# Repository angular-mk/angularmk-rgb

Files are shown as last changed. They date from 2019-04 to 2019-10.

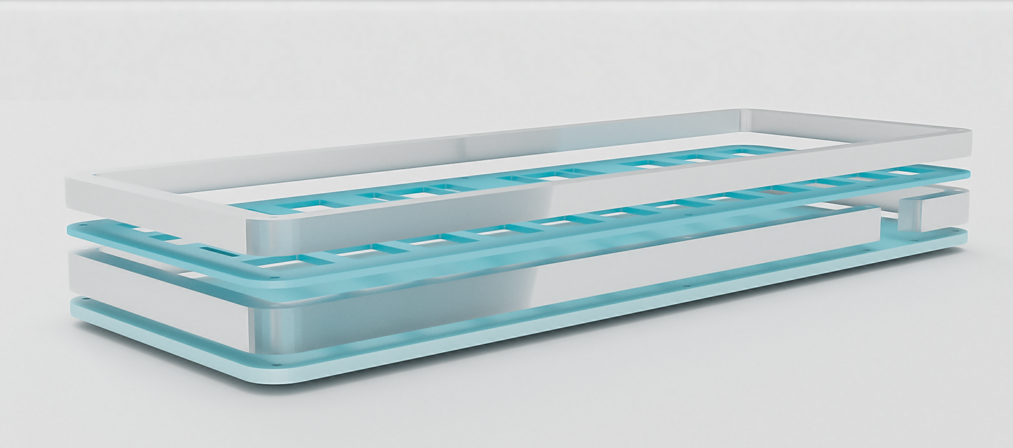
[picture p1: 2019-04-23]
Case Design/Render 2.png

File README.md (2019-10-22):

# angularmk-rgb
## Angular RGB Mechanical Keyboard

Image of the Keyboard

### Description

The AngularRGB is a, minimalistic, 40% keyboard that supports perkey RGB Lighting. We've noticed that there are no purchasing options for anyone interested in a rgb per key backlit keyboard, so we decided to create one.
[Website Description](https://angularmk.xyz/angular-rgb/)

Keyboard PCB

The PCB consists of a 4x12 matrix layed out as a COL to ROW diode configuration with a staggered design. Additionally, there are slots cut out on the board to provide the space for the WS2812B-Mini RGB LEDs that provide the lighting. There are also numerous protection features, such as ESD protections for both the data lines aswell as the power lines; fueses protecting the precious microcontroller in a case of short circuit; and many more.

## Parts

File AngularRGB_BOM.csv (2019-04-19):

Id | Designator | Package | Quantity | Designation | Supplier and ref
1 | SW28,SW31,SW2,SW3,SW4,SW5,SW6,SW7,SW8,SW9,SW10,SW11,SW12,SW13,SW14,SW15,SW16,SW17,SW18,SW19,SW20,SW21,SW22,SW23,SW24,SW25,SW26,SW27,SW29,SW30,SW32,SW33 | MX-1U | 32 | MX_1U
2 | Y1 | Crystal_SMD_3225-4Pin_3.2x2.5mm | 1 | Crystal_GND24
3 | C1,C5 | C_0603_1608Metric | 2 | 1u
4 | C2,C3 | C_0603_1608Metric | 2 | 20pF
5 | C4,C6,C7,C8,C9,C10,C11,C12,C13,C14,C15,C16 | C_0603_1608Metric | 12 | 100n
6 | D1 | D_SOD-123F | 1 | D
7 | D2,D3,D4,D5,D6,D7,D8,D9,D10,D11,D12,D13,D14,D15,D16,D17,D18,D19,D20,D21,D22,D23,D24,D25,D26,D27,D28,D29,D30,D31,D32,D33,D34,D35,D36,D37,D38,D39,D40,D41,D42 | D_SOD-123 | 41 | D
8 | F1 | Fuse_0603_1608Metric | 1 | Fuse
9 | R1,R2,R3,R4 | R_0603_1608Metric | 4 | 5k1
10 | R5,R6 | R_0603_1608Metric | 2 | 22
11 | SW1.25U1,SW1.25U2,SW1.25U3,SW1.25U4,SW1.25U5,SW1.25U6 | MX_1.25U | 6 | MX_1.25U
12 | SW1.75U1,SW1.75U2 | MX-1.75U | 2 | MX_1.75U
13 | U1 | QFN-44-1EP_7x7mm_P0.5mm_EP5.2x5.2mm | 1 | ATmega32U4-MU
14 | U2 | SOT-23-6 | 1 | USB6B1
15 | USB1 | HRO-TYPE-C-31-M-12-Assembly | 1 | HRO-TYPE-C-31-M-12
16 | SW2.25U1 | MX-2.25U | 1 | MX_2.25U
17 | SW2.75U1 | MX-2.75U | 1 | MX_2.75U
18 | SW1 | SPST-NO-4 | 1 | SW_Push
19 | H1,H2,H3,H4,H5,H6,H7,H8,H9,H10 | MountingHole_2.2mm_M2_DIN965_Pad | 10 | MountingHole_Pad
20 | LED1,LED5,LED8,LED12,LED16,LED20,LED24,LED28,LED32,LED36,LED40,LED43,LED2,LED6,LED9,LED13,LED17,LED21,LED25,LED29,LED33,LED37,LED44,LED3,LED10,LED14,LED18,LED22,LED26,LED30,LED34,LED38,LED41,LED45,LED4,LED7,LED11,LED19,LED23,LED27,LED31,LED35,LED39,LED42,LED46 | REVERSE_LED | 45 | WS2812
21 | J1 | PinSocket_1x09_P2.54mm_Vertical | 1 | Conn_01x09_Male
22 | TP1,TP2 | TestPoint_Pad_D2.0mm | 2 | TestPoint

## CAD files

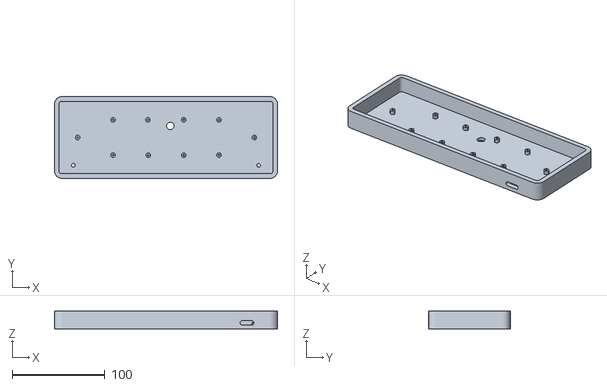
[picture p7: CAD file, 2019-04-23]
Case Design/Multilayer Sandwich Case/AlCase High Profile.stl
240.5 x 88.2 x 19.0

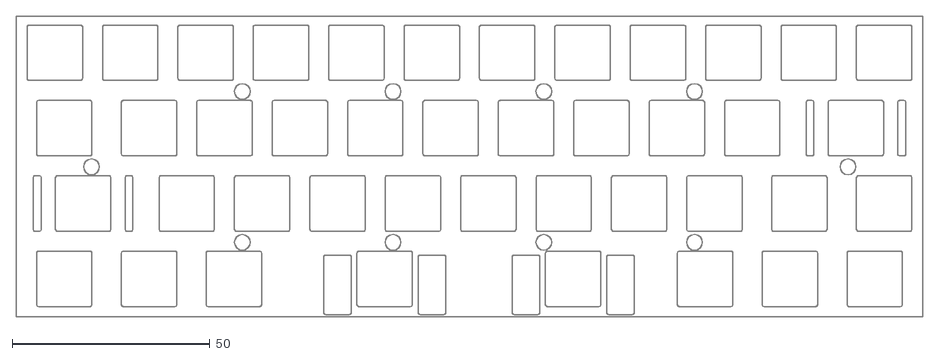
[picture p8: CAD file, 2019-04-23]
Case Design/Top_Plate.dxf
229.0 x 76.0

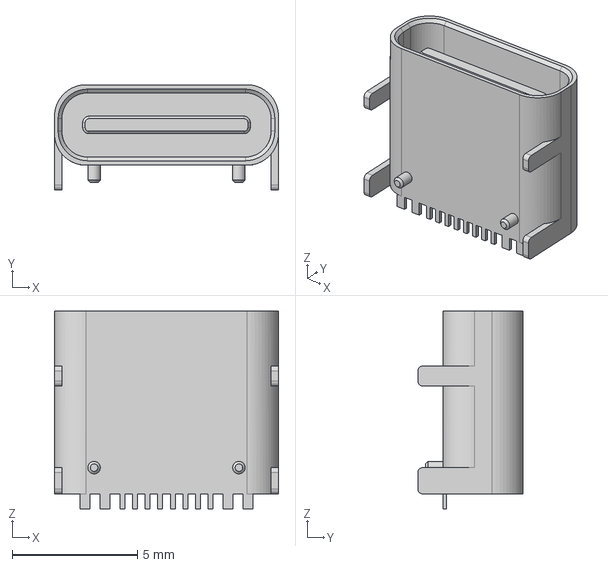
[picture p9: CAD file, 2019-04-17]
Type-C.pretty-master/HRO TYPE-C-31-M-12.step
8.94 x 4.21 x 7.90 mm

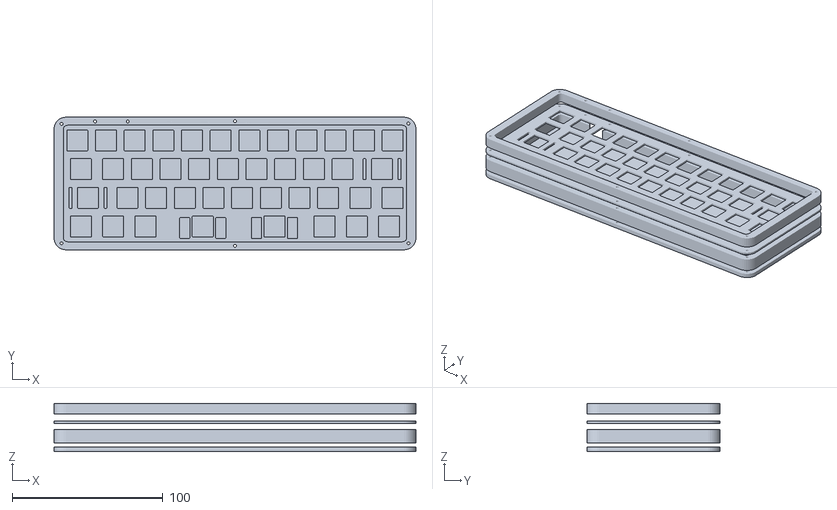
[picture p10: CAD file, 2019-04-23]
Case Design/Multilayer Sandwich Case/AlCase Sandwich.stl
240.5 x 88.2 x 32.1

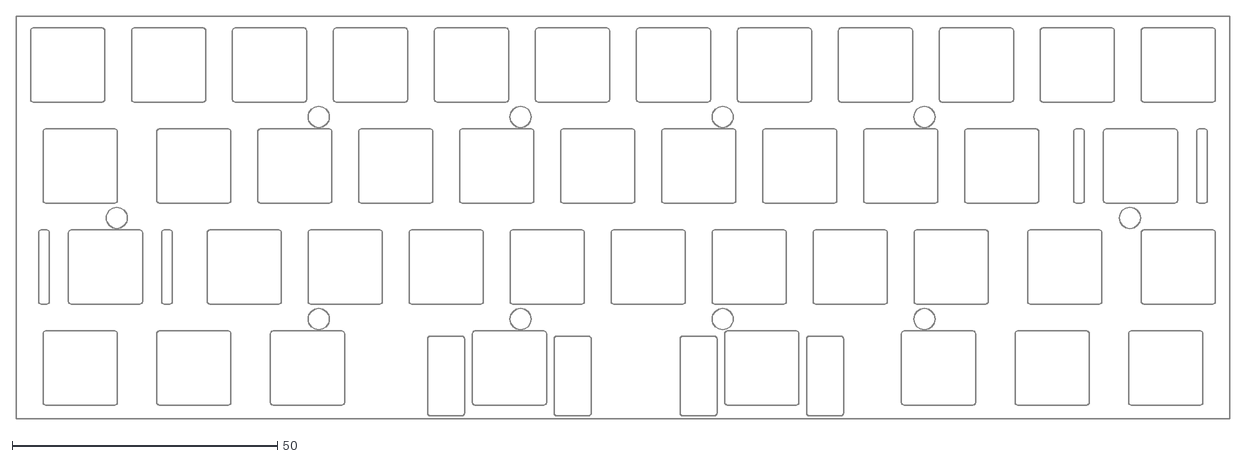
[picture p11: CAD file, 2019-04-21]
Case Design/Rounded Top Plate.dxf
229.0 x 76.0

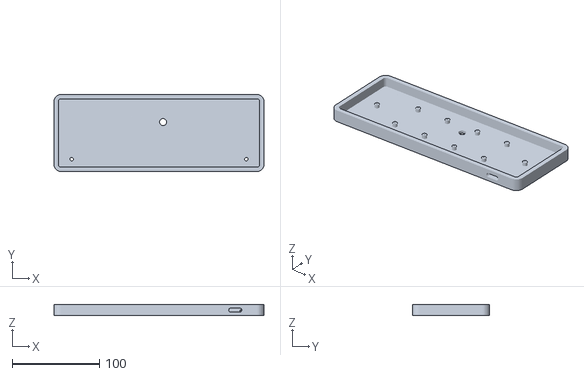
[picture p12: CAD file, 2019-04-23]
Case Design/Multilayer Sandwich Case/AlCase Low Profile.stl
240.5 x 88.2 x 13.1

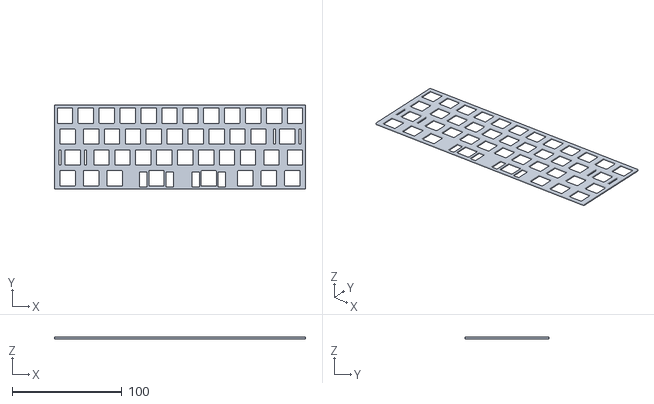
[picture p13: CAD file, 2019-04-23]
Case Design/Multilayer Sandwich Case/Plate Filled.stl
228.6 x 76.2 x 1.50

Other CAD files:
Case Design/Multilayer Sandwich Case/AlCase - Low.blend
Case Design/Multilayer Sandwich Case/AlCase - Sandwich.blend
Case Design/Multilayer Sandwich Case/AlCase.blend

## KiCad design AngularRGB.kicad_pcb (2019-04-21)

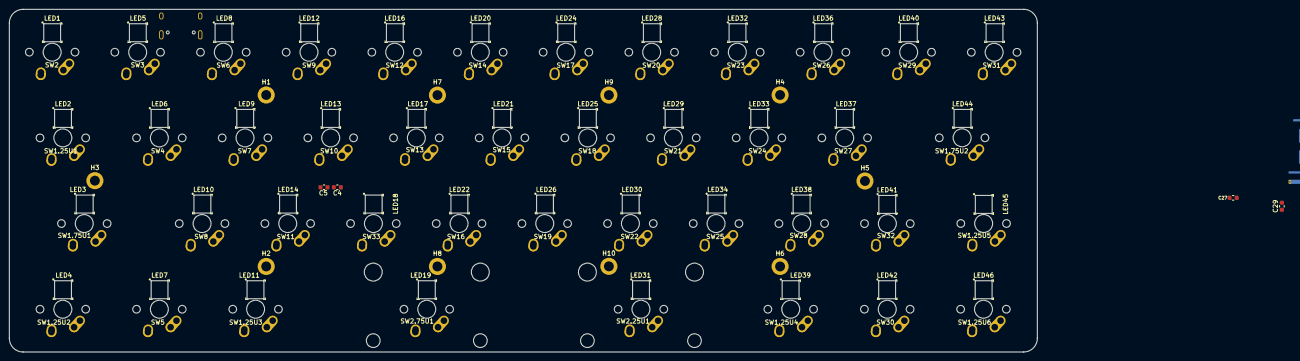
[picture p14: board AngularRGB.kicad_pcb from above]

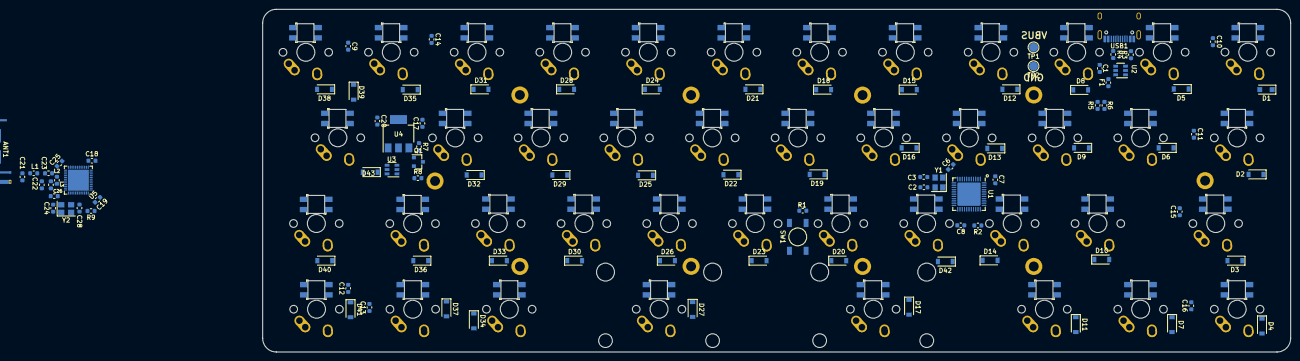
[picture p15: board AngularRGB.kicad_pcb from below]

Board: 4 copper layers, 228.6 x 76.2 mm, 192 parts (94 on the bottom side), 135 nets, no tracks yet.

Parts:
ANT1: SWRA117D; Texas_SWRA117D_2.4GHz_Right
C1, C5, C17, C20: 1u; C_0603_1608Metric
C2, C3: 20pF; C_0603_1608Metric
C4, C6, C7, C8, C9, C10, C11, C12, C13, C14, C15, C16, C18, C19, C25: 100n; C_0603_1608Metric
C21: 1.5pF; C_0603_1608Metric
C22: 1.0pF; C_0603_1608Metric
C23: 2.2pF; C_0603_1608Metric
C24, C28: 12pF; C_0603_1608Metric
C26: 2.2nF; C_0603_1608Metric
C27: 47n; C_0603_1608Metric
C29: 1.0n; C_0603_1608Metric
D1: D; D_SOD-123F
D2, D3, D4, D5, D6, D7, D8, D9, D10, D11, D12, D13, D14, D15, D16, D17, D18, D19, D20, D21, D22, D23, D24, D25, D26, D27, D28, D29, D30, D31, D32, D33, D34, D35, D36, D37, D38, D39, D40, D41, D42, D43: D; D_SOD-123
F1: Fuse; Fuse_0603_1608Metric
H1, H2, H3, H4, H5, H6, H7, H8, H9, H10: MountingHole_Pad; MountingHole_2.2mm_M2_DIN965_Pad
L1: 3.3nH; L_0603_1608Metric
L2: 4.7nH; L_0603_1608Metric
L3: 10nH; L_0603_1608Metric
LED1, LED2, LED3, LED4, LED5, LED6, LED7, LED8, LED9, LED10, LED11, LED12, LED13, LED14, LED16, LED17, LED18, LED19, LED20, LED21, LED22, LED24, LED25, LED26, LED28, LED29, LED30, LED31, LED32, LED33, LED34, LED36, LED37, LED38, LED39, LED40, LED41, LED42, LED43, LED44, LED45, LED46: WS2812; REVERSE_LED
Q1: BSS138; SOT-23
R1, R2, R3, R4, R7, R8, R9: 5k1; R_0603_1608Metric
R5, R6: 22; R_0603_1608Metric
SW1: SW_Push; SPST-NO-4
SW1.25U1, SW1.25U2, SW1.25U3, SW1.25U4, SW1.25U5, SW1.25U6: MX_1.25U
SW1.75U1, SW1.75U2: MX_1.75U; MX-1.75U
SW2, SW3, SW4, SW5, SW6, SW7, SW8, SW9, SW10, SW11, SW12, SW13, SW14, SW15, SW16, SW17, SW18, SW19, SW20, SW21, SW22, SW23, SW24, SW25, SW26, SW27, SW28, SW29, SW30, SW31, SW32, SW33: MX_1U; MX-1U
SW2.25U1: MX_2.25U; MX-2.25U
SW2.75U1: MX_2.75U; MX-2.75U
TP1, TP2: TestPoint; TestPoint_Pad_D2.0mm
U1: ATmega32U4-MU; QFN-44-1EP_7x7mm_P0.5mm_EP5.2x5.2mm
U2: USB6B1; SOT-23-6
U3: 74LVC2G34; SOT-23-6
U4: AMS1117-3.3; SOT-223-3_TabPin2
U5: nRF51x22-QFxx; QFN-48-1EP_6x6mm_P0.4mm_EP4.66x4.66mm
USB1: HRO-TYPE-C-31-M-12; HRO-TYPE-C-31-M-12-Assembly
Y1, Y2: Crystal_GND24; Crystal_SMD_3225-4Pin_3.2x2.5mm

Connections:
+3V3: C18.1, C19.1, C20.1, C29.1, Q1.1, R7.1, R9.1, U3.5, U4.2, U5.1, U5.12, U5.35, U5.36
/ANT: ANT1.1, C21.1, L1.1
/ANT1: C23.1, L2.1, U5.31
/ANT2: L2.2, L3.1, U5.32
/CS: D43.1, U1.29
/CS_3V: D43.2, R9.2, U5.43
/D+: R5.1, U1.4
/D-: R6.1, U1.3
/DN_PRE: U2.4, USB1.5, USB1.7
/DP_PRE: U2.6, USB1.6, USB1.8
/D_N: R6.2, U2.3
/D_P: R5.2, U2.1
/MISO: U1.11, U5.41
/MOSI: U1.10, U3.3
/MOSI_3V: U3.4, U5.42
/RST: Q1.3, R8.2, U1.1
/SCK: U1.9, U3.1
/SCK_3V: U3.6, U5.40
/SWDIO: Q1.2, R7.2, U5.23
/UCAP: C5.1, U1.6
/VBUS: F1.2, TP1.1, U2.5, USB1.2, USB1.11
/VDD_PA: C26.1, L3.2, U5.30
/XC1: C24.1, U5.37, Y2.1
/XC2: C28.1, U5.38, Y2.3
/XTAL1: C2.1, U1.17, Y1.1
/XTAL2: C3.1, U1.16, Y1.3
C0: D1.1, D2.1, D3.1, D4.1, U1.25
C1: D5.1, D6.1, D7.1, U1.26
C2: D8.1, D9.1, D10.1, D11.1, U1.27
C3: D12.1, D13.1, D14.1, U1.28
C4: D15.1, D16.1, D17.1, D42.1, U1.41
C5: D18.1, D19.1, D20.1, U1.40
C6: D21.1, D22.1, D23.1, U1.39
C7: D24.1, D25.1, D26.1, D27.1, U1.38
C8: D28.1, D29.1, D30.1, U1.37
C9: D31.1, D32.1, D33.1, D34.1, U1.36
C10: D35.1, D36.1, D37.1, U1.32
C11: D38.1, D39.1, D40.1, D41.1, U1.31
GND: ANT1.2, C1.2, C2.2, C3.2, C4.2, C5.2, C6.2, C7.2, C8.2, C9.2, C10.2, C11.2, C12.2, C13.1, C14.1, C15.1, C16.1, C17.2, C18.2, C19.2, C20.2, C21.2, C22.2, C24.2, C25.2, C26.2, C27.2, C28.2, C29.2, H1.1, H2.1, H3.1, H4.1, H5.1, H6.1, H7.1, H8.1, H9.1, H10.1, LED1.3, LED2.3, LED3.3, LED4.3, LED5.3, LED6.3, LED7.3, LED8.3, LED9.3, LED10.3, LED11.3, LED12.3, LED13.3, LED14.3, LED16.3, LED17.3, LED18.3, LED19.3, LED20.3, LED21.3, LED22.3, LED24.3, LED25.3, LED26.3, LED28.3, LED29.3, LED30.3, LED31.3, LED32.3, LED33.3, LED34.3, LED36.3, LED37.3, LED38.3, LED39.3, LED40.3, LED41.3, LED42.3, LED43.3, LED44.3, LED45.3, LED46.3, R2.2, R3.1, R4.2, SW1.1, TP2.1, U1.5, U1.15, U1.23, U1.35, U1.43, U1.45, U2.2, U3.2, U4.1, U5.13, U5.33, U5.34, U5.49, USB1.1, USB1.12, USB1.13, Y1.2, Y1.4, Y2.2, Y2.4
LED_INPUT: LED1.4, U1.8
unnamed: C22.1, C23.2, L1.2
unnamed: C25.1, U5.29
unnamed: C27.1, U5.39
unnamed: D1.2, SW2.2
unnamed: D2.2, SW1.25U1.2
unnamed: D3.2, SW1.75U1.2
unnamed: D4.2, SW1.25U2.2
unnamed: D5.2, SW3.2
unnamed: D6.2, SW4.2
unnamed: D7.2, SW5.2
unnamed: D8.2, SW6.2
unnamed: D9.2, SW7.2
unnamed: D10.2, SW8.2
unnamed: D11.2, SW1.25U3.2
unnamed: D12.2, SW9.2
unnamed: D13.2, SW10.2
unnamed: D14.2, SW11.2
unnamed: D15.2, SW12.2
unnamed: D16.2, SW13.2
unnamed: D17.2, SW2.75U1.2
unnamed: D18.2, SW14.2
unnamed: D19.2, SW15.2
unnamed: D20.2, SW16.2
unnamed: D21.2, SW17.2
unnamed: D22.2, SW18.2
unnamed: D23.2, SW19.2
unnamed: D24.2, SW20.2
unnamed: D25.2, SW21.2
unnamed: D26.2, SW22.2
unnamed: D27.2, SW2.25U1.2
unnamed: D28.2, SW23.2
unnamed: D29.2, SW24.2
unnamed: D30.2, SW25.2
unnamed: D31.2, SW26.2
unnamed: D32.2, SW27.2
unnamed: D33.2, SW28.2
unnamed: D34.2, SW1.25U4.2
unnamed: D35.2, SW29.2
unnamed: D36.2, SW32.2
unnamed: D37.2, SW30.2
unnamed: D38.2, SW31.2
unnamed: D39.2, SW1.75U2.2
unnamed: D40.2, SW1.25U5.2
unnamed: D41.2, SW1.25U6.2
unnamed: D42.2, SW33.2
unnamed: LED1.2, LED5.4
unnamed: LED2.2, LED6.4
unnamed: LED2.4, LED43.2
unnamed: LED3.4, LED44.2
unnamed: LED4.2, LED7.4
unnamed: LED4.4, LED45.2
unnamed: LED5.2, LED8.4
unnamed: LED6.2, LED9.4
unnamed: LED10.2, LED14.4
unnamed: LED3.2, LED10.4
unnamed: LED11.2, LED19.4
unnamed: LED7.2, LED11.4
unnamed: LED12.2, LED16.4
unnamed: LED8.2, LED12.4
unnamed: LED13.2, LED17.4
unnamed: LED9.2, LED13.4
unnamed: LED14.2, LED18.4
unnamed: LED16.2, LED20.4
unnamed: LED17.2, LED21.4
unnamed: LED18.2, LED22.4
unnamed: LED19.2, LED31.4
unnamed: LED20.2, LED24.4
unnamed: LED21.2, LED25.4
unnamed: LED22.2, LED26.4
unnamed: LED24.2, LED28.4
unnamed: LED25.2, LED29.4
unnamed: LED26.2, LED30.4
unnamed: LED28.2, LED32.4
unnamed: LED29.2, LED33.4
unnamed: LED30.2, LED34.4
unnamed: LED31.2, LED39.4
unnamed: LED32.2, LED36.4
unnamed: LED33.2, LED37.4
unnamed: LED34.2, LED38.4
unnamed: LED36.2, LED40.4
unnamed: LED37.2, LED44.4
unnamed: LED38.2, LED41.4
unnamed: LED39.2, LED42.4
unnamed: LED40.2, LED43.4
unnamed: LED41.2, LED45.4
unnamed: LED42.2, LED46.4
unnamed: R1.2, SW1.2, U1.13
unnamed: R2.1, U1.33
unnamed: R3.2, USB1.4
unnamed: R4.1, USB1.10
R0: SW2.1, SW3.1, SW6.1, SW9.1, SW12.1, SW14.1, SW17.1, SW20.1, SW23.1, SW26.1, SW29.1, SW31.1, U1.22
R1: SW1.25U1.1, SW1.75U2.1, SW4.1, SW7.1, SW10.1, SW13.1, SW15.1, SW18.1, SW21.1, SW24.1, SW27.1, U1.21
R2: SW1.25U5.1, SW1.75U1.1, SW8.1, SW11.1, SW16.1, SW19.1, SW22.1, SW25.1, SW28.1, SW32.1, SW33.1, U1.20
R3: SW1.25U2.1, SW1.25U3.1, SW1.25U4.1, SW1.25U6.1, SW2.25U1.1, SW2.75U1.1, SW5.1, SW30.1, U1.12
VCC: C1.1, C4.1, C6.1, C7.1, C8.1, C9.1, C10.1, C11.1, C12.1, C13.2, C14.2, C15.2, C16.2, C17.1, F1.1, LED1.1, LED2.1, LED3.1, LED4.1, LED5.1, LED6.1, LED7.1, LED8.1, LED9.1, LED10.1, LED11.1, LED12.1, LED13.1, LED14.1, LED16.1, LED17.1, LED18.1, LED19.1, LED20.1, LED21.1, LED22.1, LED24.1, LED25.1, LED26.1, LED28.1, LED29.1, LED30.1, LED31.1, LED32.1, LED33.1, LED34.1, LED36.1, LED37.1, LED38.1, LED39.1, LED40.1, LED41.1, LED42.1, LED43.1, LED44.1, LED45.1, LED46.1, R1.1, R8.1, U1.2, U1.7, U1.14, U1.24, U1.34, U1.44, U4.3

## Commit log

2019-04-16 MCU Connections
    [AngularRGB.sch]
2019-04-16 USB Sch
    [AngularRGB.sch]
2019-04-17 USB Port
    [AngularRGB.sch]
2019-04-17 Matrix Layout
    [AngularRGB.sch]
2019-04-17 Addded PCB Footprints
2019-04-17 Footprint Linking
    [AngularRGB.sch, HRO TYPE-C-31-M-12.step]
2019-04-18 WS2812B-Mini Symbole
    [AngularRGB.sch]
2019-04-18 Reverse mount WS2812B LED Footprint
    [AngularRGB.kicad_pcb, AngularRGB.sch]
2019-04-18 Led matrix
    [AngularRGB.sch, LedMatrix.sch]
2019-04-18 LED Matrix Sch
    [AngularRGB.sch]
2019-04-18 LED Matrix Placement
    [AngularRGB.kicad_pcb, AngularRGB.sch]
2019-04-18 LED Matrix Footprint swap
    [AngularRGB.kicad_pcb]
2019-04-18 Matrix Connections
    [AngularRGB.kicad_pcb, AngularRGB.sch]
2019-04-19 Finsihed Layout
    [AngularRGB.kicad_pcb, AngularRGB.sch]
2019-04-19 Copper Pour
    [AngularRGB.kicad_pcb]
2019-04-19 Fixed LED Input
    [AngularRGB-B.Cu.gbr, AngularRGB-B.Mask.gbr, AngularRGB-B.Paste.gbr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]
2019-04-20 Top Plate Init
    [Top_Plate.dxf]
2019-04-21 Added Case Design
    [AlCase.blend, AngularRGB.kicad_pcb, AngularRGB.sch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]
2019-04-22 Added the case
    [AlCase.blend]
2019-04-23 Cleaning up
    [AlCase - Low.blend, AlCase - Sandwich.blend, AlCase.blend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]
2019-04-23 Exported CAD Files
    [AlCase - Low.blend, AlCase - Sandwich.blend, AlCase High Profile.stl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]
